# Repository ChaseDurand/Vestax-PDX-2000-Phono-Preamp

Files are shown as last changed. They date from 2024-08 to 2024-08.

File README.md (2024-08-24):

# Vestax PDX-2000 Phono Preamp
Integrated phono preamp for Vestax PDX-2000 turntables.

<p align='center'>
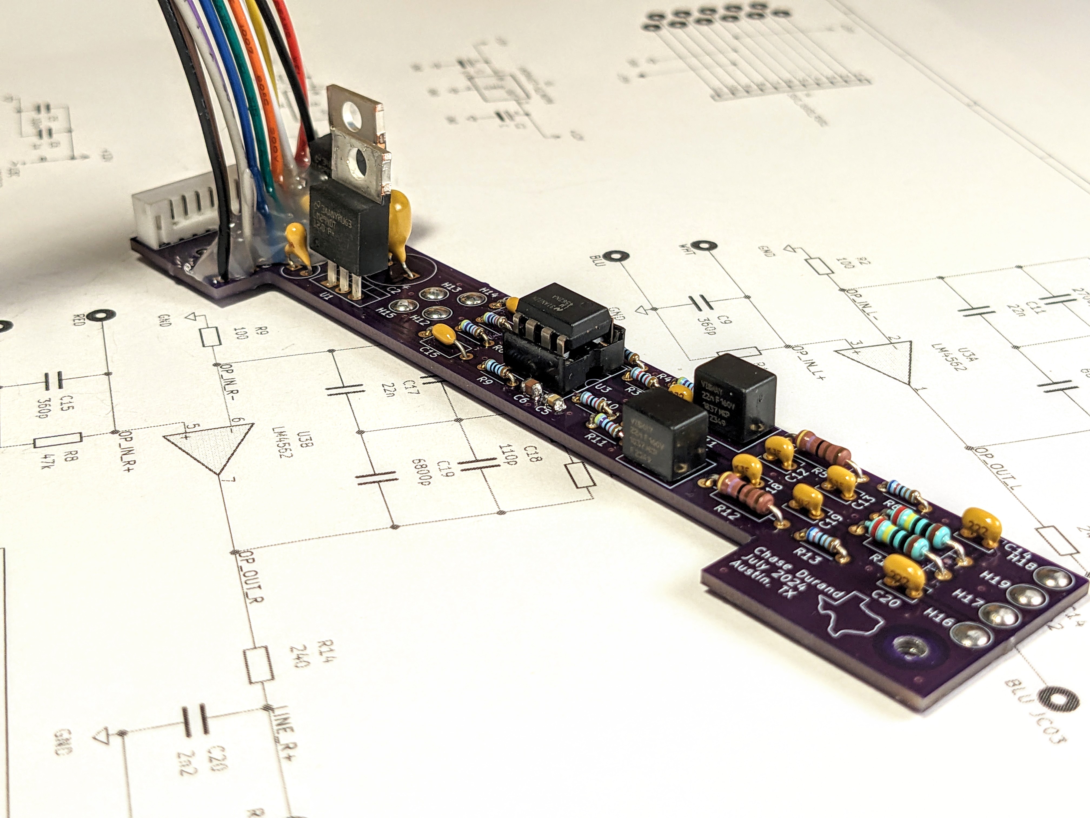
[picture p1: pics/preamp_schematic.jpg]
Phono preamp on schematic
    
</p>

Specs:
* Gain ~42.7dB at 1kHz.
* Loading 47kΩ, 360pF.
* Simulated amplitude within +/-0.05dB of RIAA.
* Actual amplitude within +/-0.5dB of RIAA.
* Left/right channel amplitude within +/-0.22dB.
* Left/right channel phase within +/-0.67°.

This amplifier is designed for moving magnet catridges- specifically around the Shure M44-7 and Ortofon Mix Concorde Mk II.

The board uses existing PCB screws on board P100 to mount in the chasis. The existing cable on J704 is re-routed to J4, and new wires and an 11-pin JST connector go to J704. The tonearm wires are routed to the input section of the PCB, and new wires connect the output of the amplifier to the original output PCB and RCA jacks. Board taps into internal +15V/-15V/GND for power (with 12V regulators for ripple reduction).

<p align='center'>
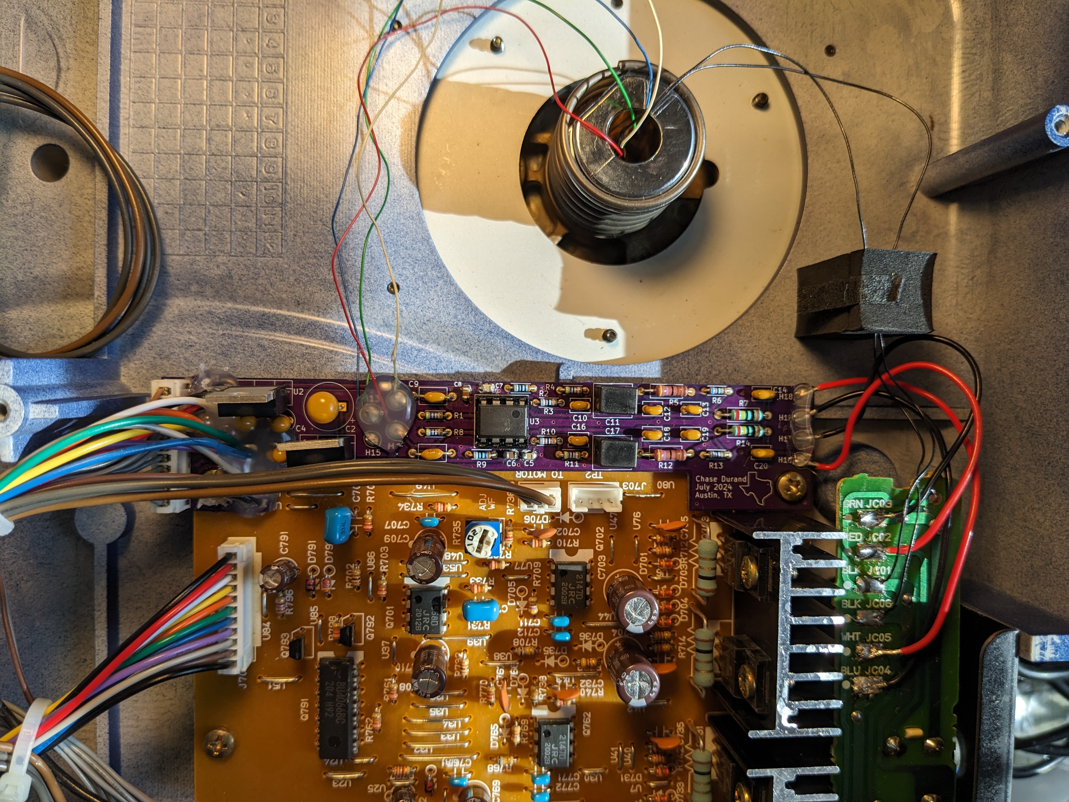
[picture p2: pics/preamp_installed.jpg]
Phono preamp installed
    
</p>

Overall performance is very good with minimal deviations from RIAA, simulation, and left/right channels. Note that some plots below use a heavily magnified delta on the right axis.

The [LTspice simulation](spice/) closely follows the RIAA amplitude curve within +/-0.05dB:

<p align='center'>
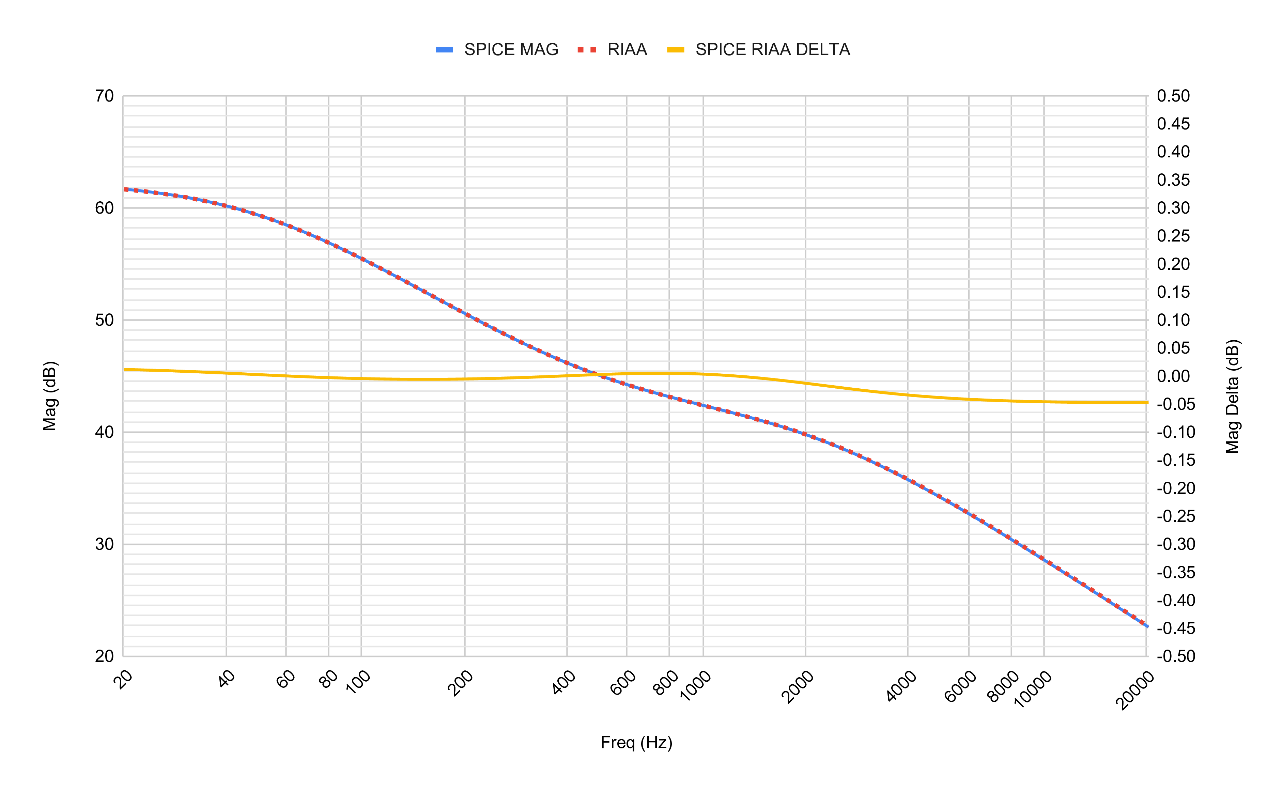
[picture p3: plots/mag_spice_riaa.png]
    
</p>

Simulations with 1% tolerance parts give a max amplitude error of +/-0.15dB:

<p align='center'>
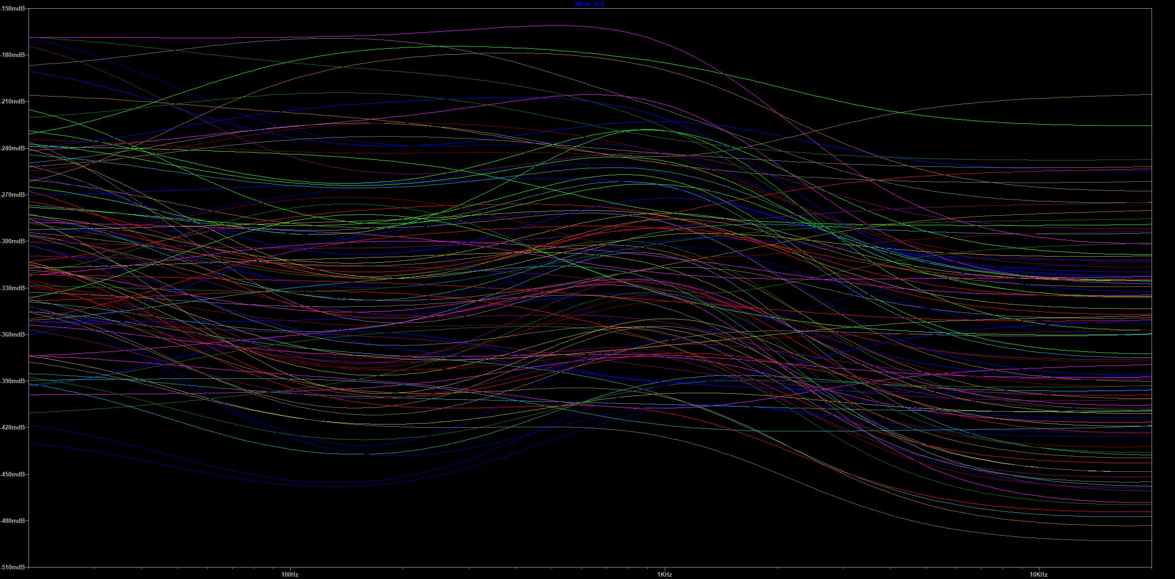
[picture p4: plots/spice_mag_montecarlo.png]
    
</p>

The actual amplitude error is within +/-0.5dB, with the majority being within +/-0.1dB:

<p align='center'>
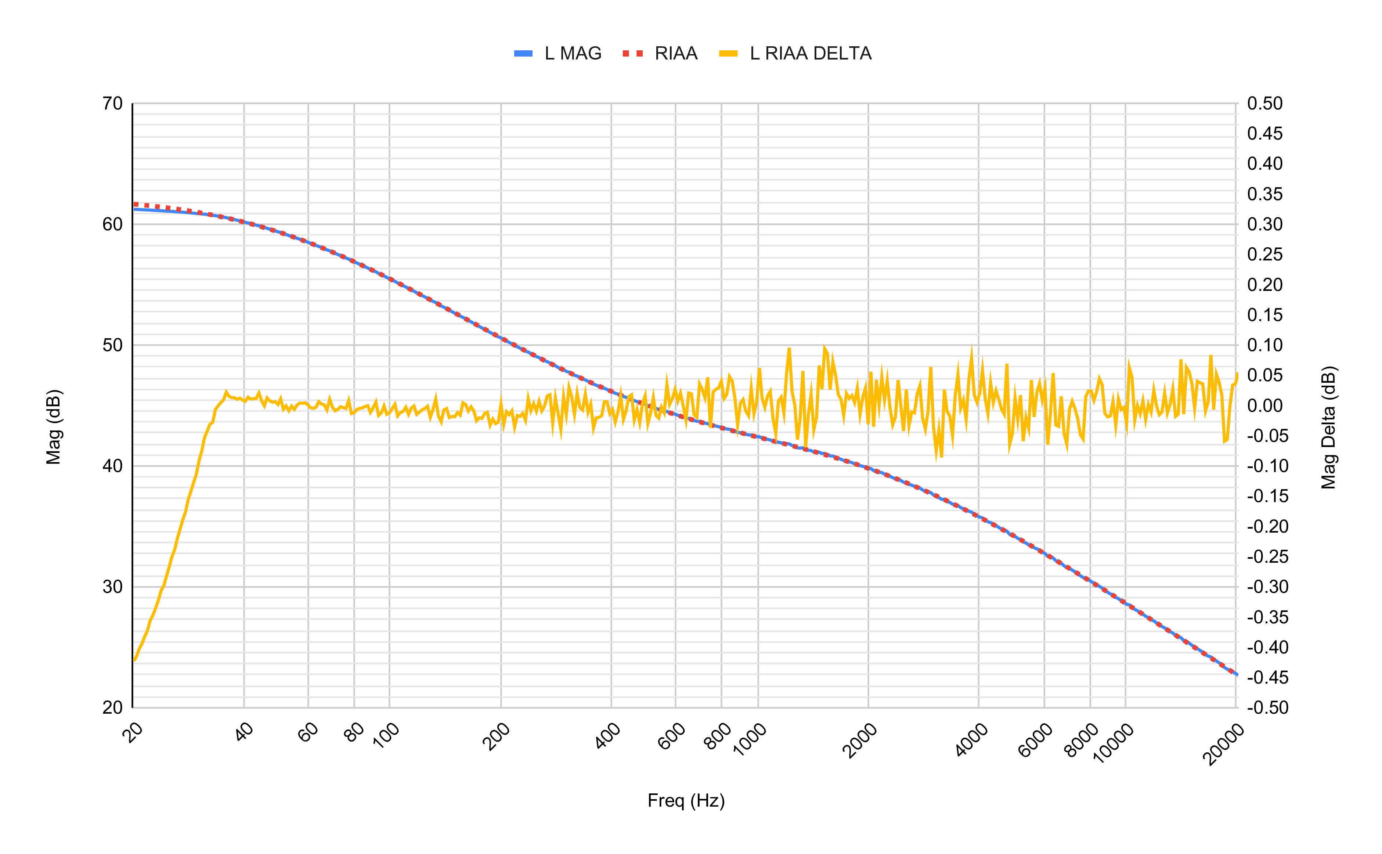
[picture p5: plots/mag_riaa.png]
    
</p>

The frequency response of the left and right channels is closely matched:

<p align='center'>
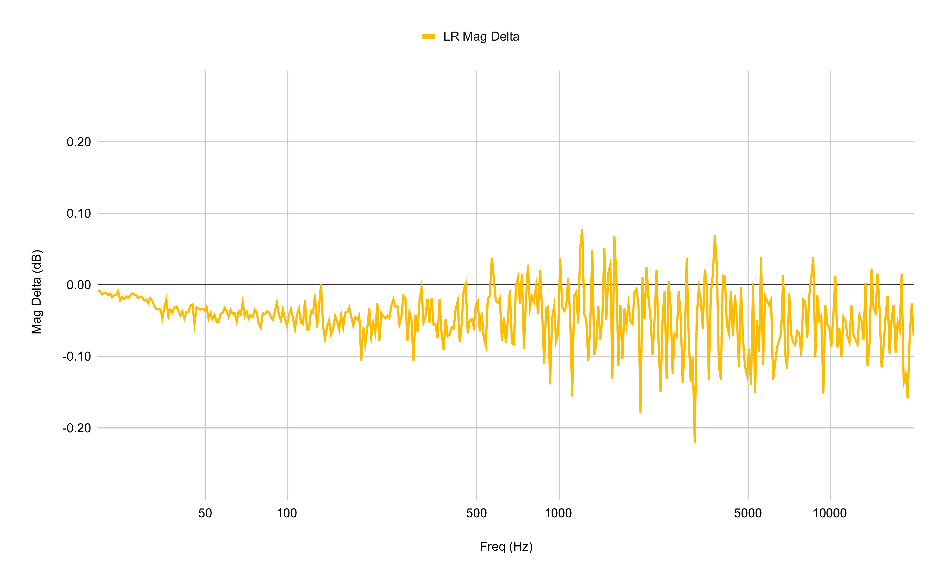
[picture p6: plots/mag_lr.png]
    
</p>

The phase is very similar to the simulation:

<p align='center'>
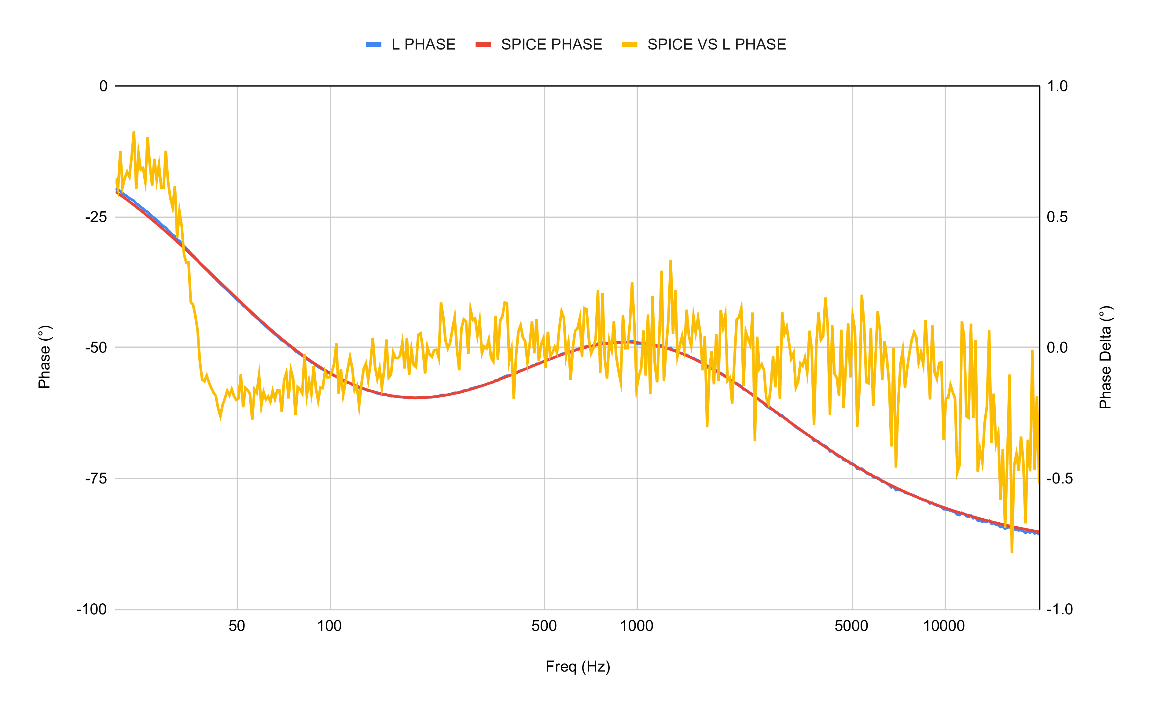
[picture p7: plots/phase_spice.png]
    
</p>

The phase response of the left and right channels is closely matched:

<p align='center'>
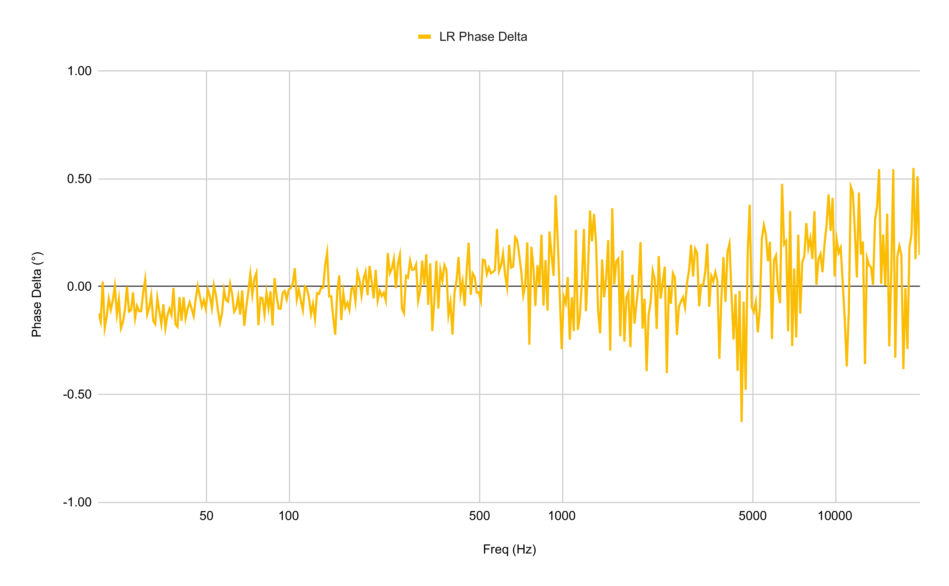
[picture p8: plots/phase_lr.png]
    
</p>

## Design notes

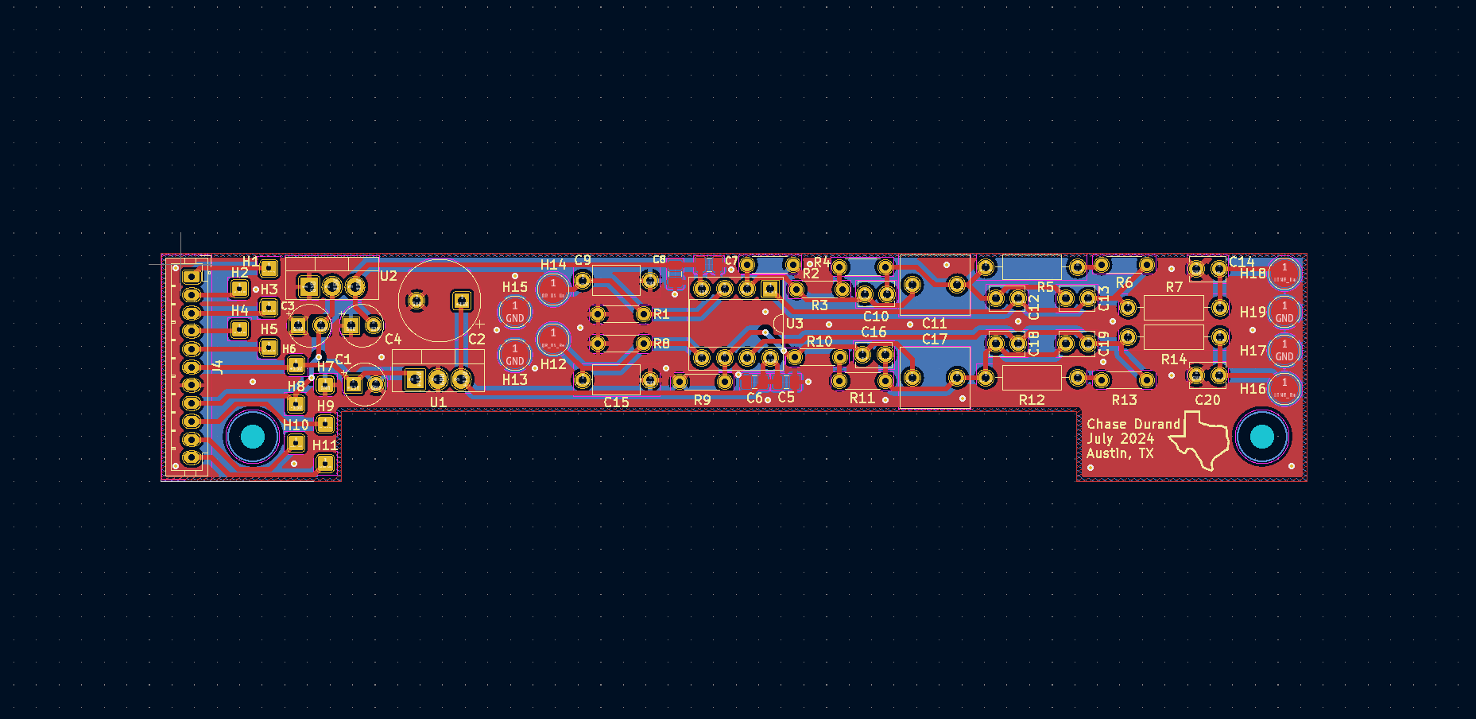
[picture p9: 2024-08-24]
pics/preamp_pcb.PNG

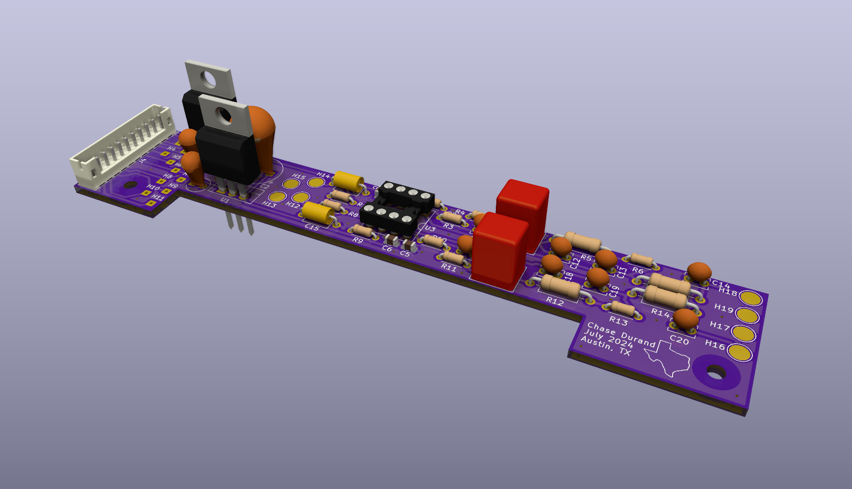
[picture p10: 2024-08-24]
pics/preamp_pcb_3d.PNG

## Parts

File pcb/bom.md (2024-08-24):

| Part Number | Mfr. | Mfr.	 Part Number | Description | Quantity |
| :--- | :---| :--- | :--- | ---: |
|	C1	|	KYOCERA AVX 	|	TAP474K035GSB	|	Tantalum Capacitors - Solid Leaded Tantalum Capacitors - Solid Leaded 35V 0.47uF 10% ESR=1 3 Ohm	|	1	|
|	C10, C16	|	KEMET	|	C315C272F3G5TA	|	Multilayer Ceramic Capacitors MLCC - Leaded Multilayer Ceramic Capacitors MLCC - Leaded 25V 2700pF C0G 1% LS=2.54mm	|	2	|
|	C11, C17	|	Vishay	|	MKP1837322161G	|	Film Capacitors Film Capacitors .022uF 160volt 1%	|	2	|
|	C12, C18	|	KEMET	|	C320C111F3G5TA	|	Multilayer Ceramic Capacitors MLCC - Leaded Multilayer Ceramic Capacitors MLCC - Leaded 25V 110pF C0G 1% LS=2.54mm	|	2	|
|	C13, C19	|	KEMET	|	C315C682F3G5TA	|	Multilayer Ceramic Capacitors MLCC - Leaded Multilayer Ceramic Capacitors MLCC - Leaded 25V 6800pF C0G 1% LS=2.54mm	|	2	|
|	C134, C20	|	KEMET	|	C320C222F1G5TA	|	Multilayer Ceramic Capacitors MLCC - Leaded Multilayer Ceramic Capacitors MLCC - Leaded 100V 2200pF C0G 1% LS=2.54mm	|	2	|
|	C2	|	KYOCERA AVX 	|	TAP336M035CCS	|	Tantalum Capacitors - Solid Leaded Tantalum Capacitors - Solid Leaded 35V 33uF 20% ESR=1 O hm	|	1	|
|	C3, C4	|	KYOCERA AVX 	|	TAP225K025SRW	|	Tantalum Capacitors - Solid Leaded Tantalum Capacitors - Solid Leaded 25V 2.2uF 10% ESR=6 Ohm	|	2	|
|	C5, C7	|	KYOCERA AVX 	|	KAM21BR71H104JT	|	Multilayer Ceramic Capacitors MLCC - SMD/SMT Multilayer Ceramic Capacitors MLCC - SMD/SMT 50V .1uF X7R 0805 5% AEC-Q200	|	2	|
|	C6, C8	|	KYOCERA AVX 	|	KAF21KR71H105KU	|	Multilayer Ceramic Capacitors MLCC - SMD/SMT Multilayer Ceramic Capacitors MLCC - SMD/SMT 50V 1uF X7R 0805 10% AEC-Q200 FLEXITERM	|	2	|
|	C9, C15	|	KEMET	|	C410C361F3G5TA	|	Multilayer Ceramic Capacitors MLCC - Leaded Multilayer Ceramic Capacitors MLCC - Leaded 25V 360pF C0G 1%	|	2	|
|	J4	|	BOJOUL	|		|	12 Sets JST PH 2.0mm 11 Pin Male Connector and 26AWG Female Connector Plug with Wire Cable 20cm Used in PCB Toys Household Appliances etc	|	1	|
|	R1, R8, R5, R12	|	Vishay	|	MRS16000C4702FCT00	|	Thin Film Resistors - Through Hole Thin Film Resistors - Through Hole 0.4watt 47Kohm 1%	|	4	|
|	R2, R9	|	Vishay	|	MBA02040C1000FRP00	|	Metal Film Resistors - Through Hole Metal Film Resistors - Through Hole .4watt 100ohms 1% 1/8watt body size	|	2	|
|	R3, R10	|	Vishay	|	MBA02040C8202FRP00	|	Metal Film Resistors - Through Hole Metal Film Resistors - Through Hole .4watt 82Kohms 1% 1/8watt body size	|	2	|
|	R5, R12	|	KEMET	|	CCF554K70FKE36	|	Metal Film Resistors - Through Hole Metal Film Resistors - Through Hole CCF-55 4.7K 1% T-1 E36 e3	|	2	|
|	R6, R13	|	Vishay	|	MBA02040C6201FRP00	|	Metal Film Resistors - Through Hole Metal Film Resistors - Through Hole .4watt 6.2Kohms 1% 1/8watt body size	|	2	|
|	R7, R14	|	Vishay	|	SFR2500002400FR500	|	Metal Film Resistors - Through Hole Metal Film Resistors - Through Hole 400mW 240ohms 1% SFR55 Historical p/n	|	2	|
|	U1	|	Texas Instruments	|	LM2940T-12.0/NOPB	|	LDO Voltage Regulators LDO Voltage Regulators 1A LDO REG	|	1	|
|	U2	|	Texas Instruments	|	LM2990T-12/NOPB	|	LDO Voltage Regulators LDO Voltage Regulators NEG LDO REG	|	1	|
|	U3	|	Texas Instruments	|	LM4562NA/NOPB	|	Audio Amplifiers Audio Amplifiers DUAL HI PERF,HI FI AUDIO OP AMP	|	1	|

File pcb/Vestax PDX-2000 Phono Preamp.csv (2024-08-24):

Id | Designator | Package | Quantity | Designation | Supplier and ref
1 | C11,C17 | C_Rect_L7.5mm_W6.5mm_P5.00mm | 2 | 22n
2 | R3,R10 | R_Axial_DIN0204_L3.6mm_D1.6mm_P5.08mm_Horizontal | 2 | 82k
3 | R1,R8,R11,R4 | R_Axial_DIN0204_L3.6mm_D1.6mm_P5.08mm_Horizontal | 4 | 47k
4 | H5,H1,H4,H11,H2,H6,H9,H3,H8,H10,H7 | SolderWire-0.1sqmm_1x01_D0.4mm_OD1mm | 11 | MountingHole_Pad
5 | C16,C10 | C_Disc_D3.8mm_W2.6mm_P2.50mm | 2 | 2700p
6 | C13,C19 | C_Disc_D3.8mm_W2.6mm_P2.50mm | 2 | 6800p
7 | C6,C8 | C_0805_2012Metric | 2 | 1u
8 | C18,C12 | C_Disc_D3.8mm_W2.6mm_P2.50mm | 2 | 110p
9 | R13,R6 | R_Axial_DIN0204_L3.6mm_D1.6mm_P5.08mm_Horizontal | 2 | 6k2
10 | H17,H15,H14,H18,H16,H12,H19,H13 | TestPoint_Pad_D3.0mm | 8 | MountingHole_Pad
11 | C15,C9 | C_Axial_L5.1mm_D3.1mm_P7.50mm_Horizontal | 2 | 360p
12 | R14,R7 | R_Axial_DIN0207_L6.3mm_D2.5mm_P10.16mm_Horizontal | 2 | 240
13 | R12,R5 | R_Axial_DIN0207_L6.3mm_D2.5mm_P10.16mm_Horizontal | 2 | 4k7
14 | U1 | TO-220-3_Vertical | 1 | LM2940CT-12_NOPB
15 | C14,C20 | C_Disc_D3.8mm_W2.6mm_P2.50mm | 2 | 2n2
16 | C2,C4,C1,C3 | CP_Radial_Tantal_D4.5mm_P2.50mm | 4 | C
17 | U2 | TO-220-3_Vertical | 1 | LM2990SX-12
18 | C7,C5 | C_0805_2012Metric | 2 | 100n
19 | R2,R9 | R_Axial_DIN0204_L3.6mm_D1.6mm_P5.08mm_Horizontal | 2 | 100
20 | U3 | DIP-8_W7.62mm_Socket | 1 | LM4562
21 | J4 | JST_PH_B11B-PH-K_1x11_P2.00mm_Vertical | 1 | OUT_JU03_PU01

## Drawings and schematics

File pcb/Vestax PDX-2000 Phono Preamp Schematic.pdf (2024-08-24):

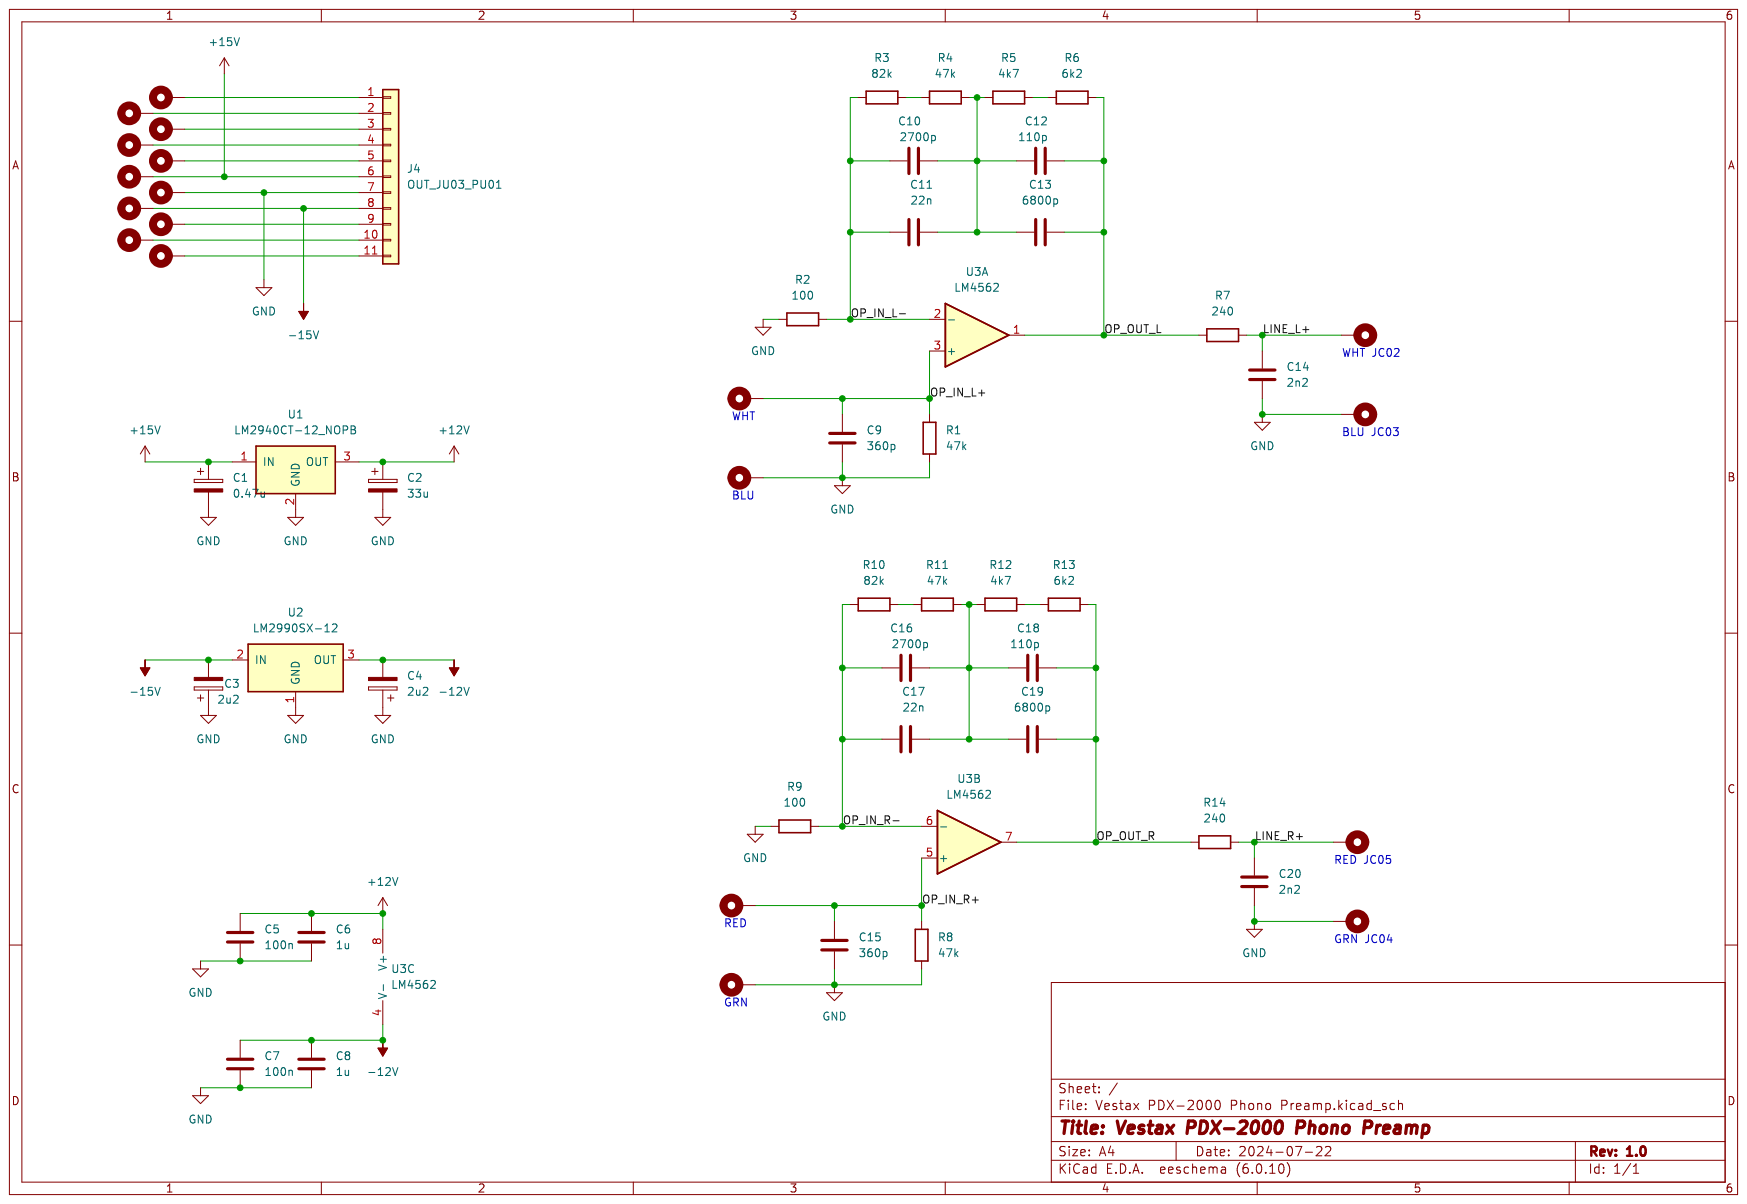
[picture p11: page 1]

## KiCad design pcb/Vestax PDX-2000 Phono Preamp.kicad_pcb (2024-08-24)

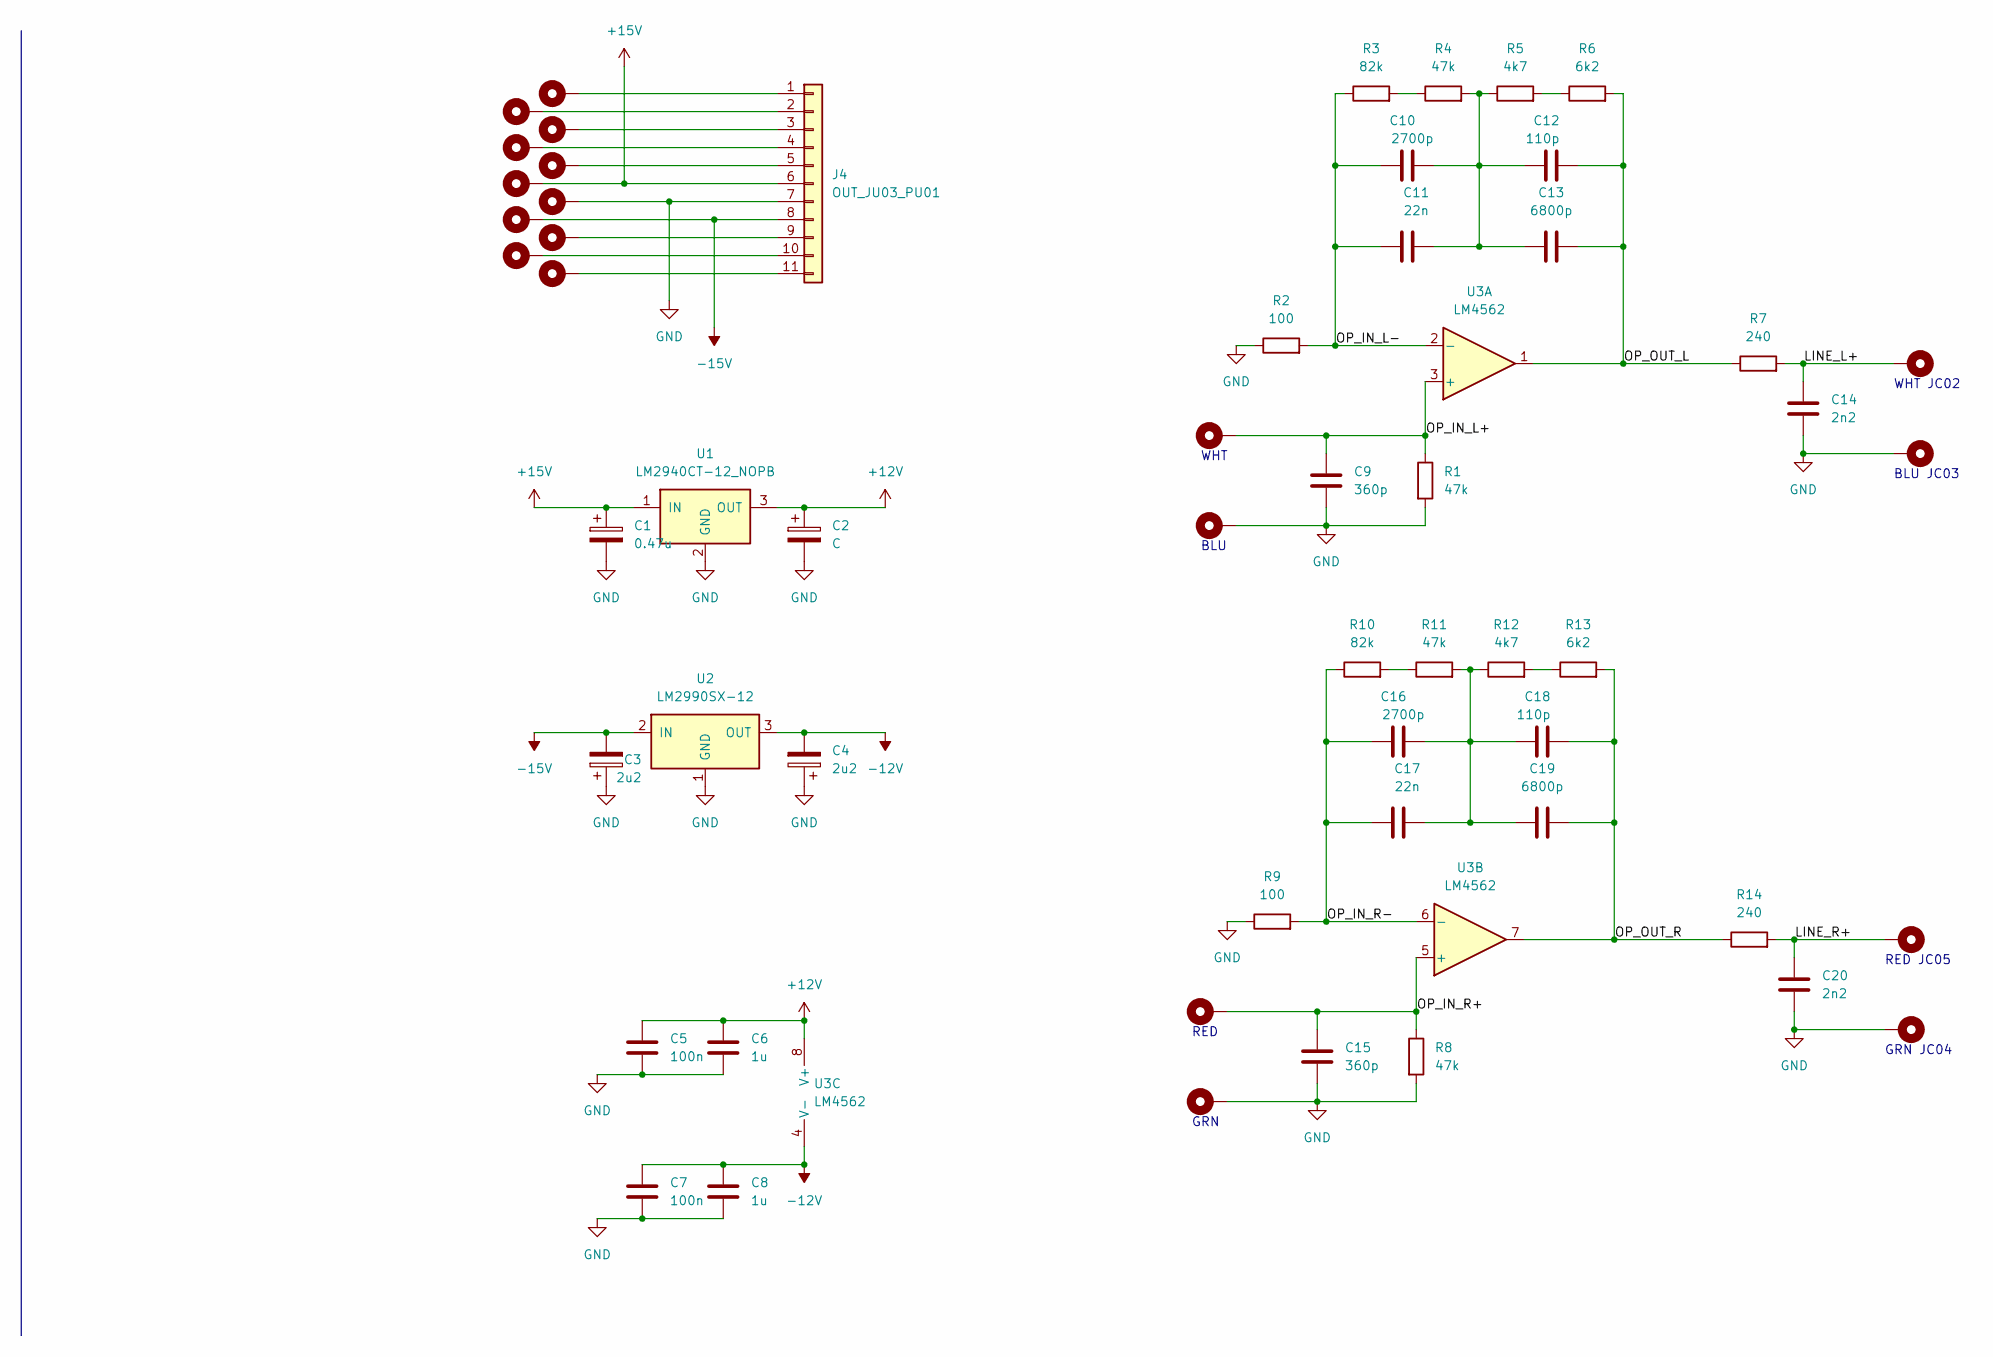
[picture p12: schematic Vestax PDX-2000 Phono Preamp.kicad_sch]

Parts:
C1: 0.47u; CP_Radial_Tantal_D4.5mm_P2.50mm
C2: C; CP_Radial_Tantal_D9.0mm_P5.00mm
C3, C4: 2u2; CP_Radial_Tantal_D4.5mm_P2.50mm
C5, C7: 100n; C_0805_2012Metric
C6, C8: 1u; C_0805_2012Metric
C9, C15: 360p; C_Axial_L5.1mm_D3.1mm_P7.50mm_Horizontal
C10, C16: 2700p; C_Disc_D3.8mm_W2.6mm_P2.50mm; Mfr. # C315C272F3G5TA
C11, C17: 22n; C_Rect_L7.5mm_W6.5mm_P5.00mm
C12, C18: 110p; C_Disc_D3.8mm_W2.6mm_P2.50mm; Mfr. # C320C111F3G5TA
C13, C19: 6800p; C_Disc_D3.8mm_W2.6mm_P2.50mm
C14, C20: 2n2; C_Disc_D3.8mm_W2.6mm_P2.50mm
H1, H2, H3, H4, H5, H6, H7, H8, H9, H10, H11: MountingHole_Pad; SolderWire-0.1sqmm_1x01_D0.4mm_OD1mm
H12, H13, H14, H15, H16, H17, H18, H19: MountingHole_Pad; TestPoint_Pad_D3.0mm
J4: OUT_JU03_PU01; JST_PH_B11B-PH-K_1x11_P2.00mm_Vertical
R1, R4, R8, R11: 47k; R_Axial_DIN0204_L3.6mm_D1.6mm_P5.08mm_Horizontal
R2, R9: 100; R_Axial_DIN0204_L3.6mm_D1.6mm_P5.08mm_Horizontal
R3, R10: 82k; R_Axial_DIN0204_L3.6mm_D1.6mm_P5.08mm_Horizontal
R5, R12: 4k7; R_Axial_DIN0207_L6.3mm_D2.5mm_P10.16mm_Horizontal
R6, R13: 6k2; R_Axial_DIN0204_L3.6mm_D1.6mm_P5.08mm_Horizontal
R7, R14: 240; R_Axial_DIN0207_L6.3mm_D2.5mm_P10.16mm_Horizontal
U1: LM2940CT-12_NOPB; TO-220-3_Vertical
U2: LM2990SX-12; TO-220-3_Vertical
U3: LM4562; DIP-8_W7.62mm_Socket; Mfr. # LM4562NA/NOPB

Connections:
+12V: C2.1, C5.2, C6.2, U1.3 (OUT), U3.8 (V+)
+15V: C1.1, H6.1, J4.6, U1.1 (IN)
-12V: C4.2, C7.2, C8.2, U2.3 (OUT), U3.4 (V-)
-15V: C3.2, H8.1, J4.8, U2.2 (IN)
/LINE_L+: C14.1, H18.1, R7.2
/LINE_R+: C20.1, H16.1, R14.2
/OP_IN_L+: C9.1, H14.1, R1.1, U3.3 (+)
/OP_IN_L-: C10.1, C11.1, R2.2, R3.1, U3.2 (-)
/OP_IN_R+: C15.1, H12.1, R8.1, U3.5 (+)
/OP_IN_R-: C16.1, C17.1, R9.2, R10.1, U3.6 (-)
/OP_OUT_L: C12.2, C13.2, R6.2, R7.1, U3.1
/OP_OUT_R: C18.2, C19.2, R13.2, R14.1, U3.7
GND: C1.2, C2.2, C3.1, C4.1, C5.1, C6.1, C7.1, C8.1, C9.2, C14.2, C15.2, C20.2, H7.1, H13.1, H15.1, H17.1, H19.1, J4.7, R1.2, R2.1, R8.2, R9.1, U1.2 (GND), U2.1 (GND)
unnamed: C10.2, C11.2, C12.1, C13.1, R4.2, R5.1
unnamed: C16.2, C17.2, C18.1, C19.1, R11.2, R12.1
unnamed: H1.1, J4.1
unnamed: H2.1, J4.2
unnamed: H3.1, J4.3
unnamed: H4.1, J4.4
unnamed: H5.1, J4.5
unnamed: H9.1, J4.9
unnamed: H10.1, J4.10
unnamed: H11.1, J4.11
unnamed: R3.2, R4.1
unnamed: R5.2, R6.1
unnamed: R10.2, R11.1
unnamed: R12.2, R13.1

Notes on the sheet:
WHT
BLU
GRN
WHT JC02
GRN JC04
RED JC05
RED
BLU JC03

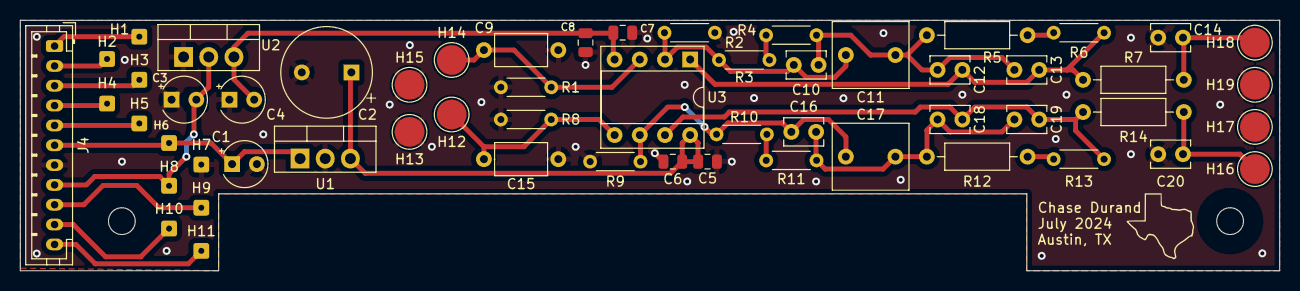
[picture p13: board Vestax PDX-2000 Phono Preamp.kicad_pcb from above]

Board: 2 copper layers, 127.0 x 25.2 mm, 59 parts (0 on the bottom side), 27 nets.

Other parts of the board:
MH1, MH1#2: MountingHole_2.7mm_M2.5

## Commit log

2024-08-24 Added kicad pcb files.
    [Vestax PDX-2000 Phono Preamp.csv, Vestax PDX-2000 Phono Preamp.kicad_pcb, Vestax PDX-2000 Phono Preamp.kicad_sch]
2024-08-24 Added preamp pcb image
2024-08-24 Added C2 value to schematic.
    [Vestax PDX-2000 Phono Preamp.kicad_sch]
2024-08-24 Added schematic pdf.
2024-08-24 Added BOM.
2024-08-24 Corrected ltspice power supply from 15 to 12.
